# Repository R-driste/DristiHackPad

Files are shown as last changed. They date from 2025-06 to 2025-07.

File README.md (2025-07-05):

# DroydPad
Here is my hackpad for Athena/Highway in Hack Club! It includes 12 switches, an oled and a rotary encoder.
- You can find the pcb gerbers and 3d print files in the sub folders. Please print my case white so I can paint it later.
- My firmware turns the hackpad into a T-9 typing pad or a shortcuts simplifier (don't have to hold down multiple keys at once). The OLED displays what is currently happening and the rotary encoder changes the brightness of the screen.
- Pictures of my schematic and cad can be found in the general_files
<p align="center">
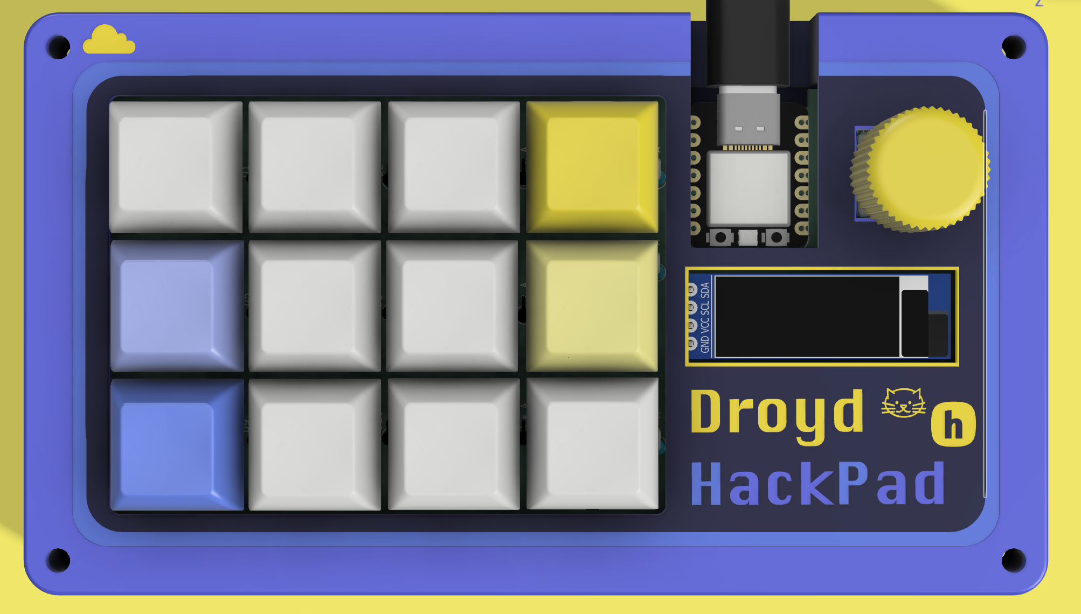
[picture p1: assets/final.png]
  
</p>

# Case CAD
Used Autodesk Fusion. In the cad_files folder I have attached my main cad file, my components (including the files needed to print the case) and components I borrowed from online (credits are below).
<p align="center">
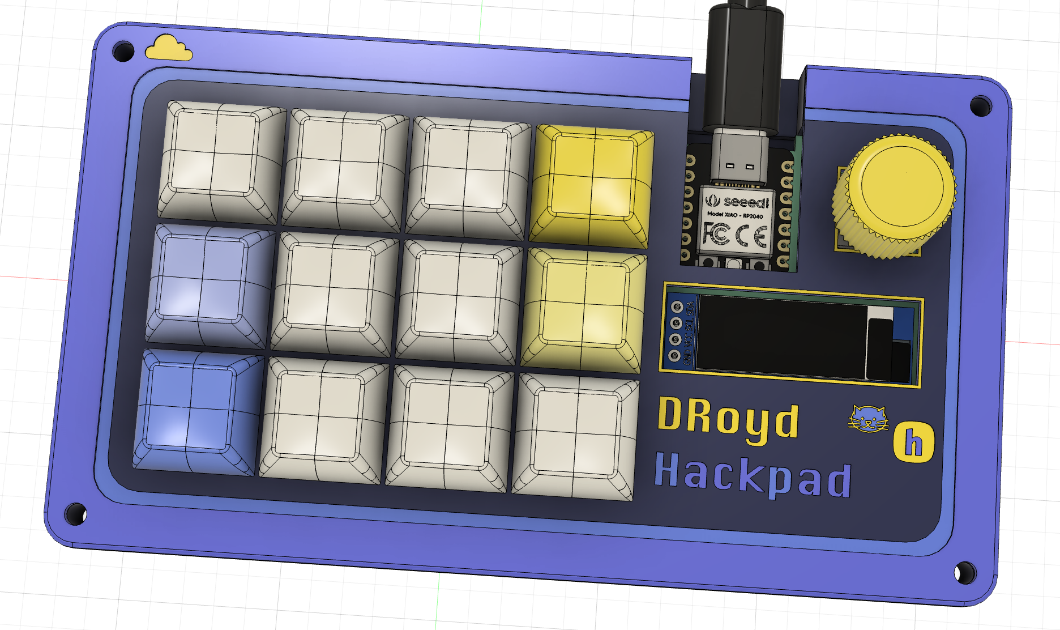
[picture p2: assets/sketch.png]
  
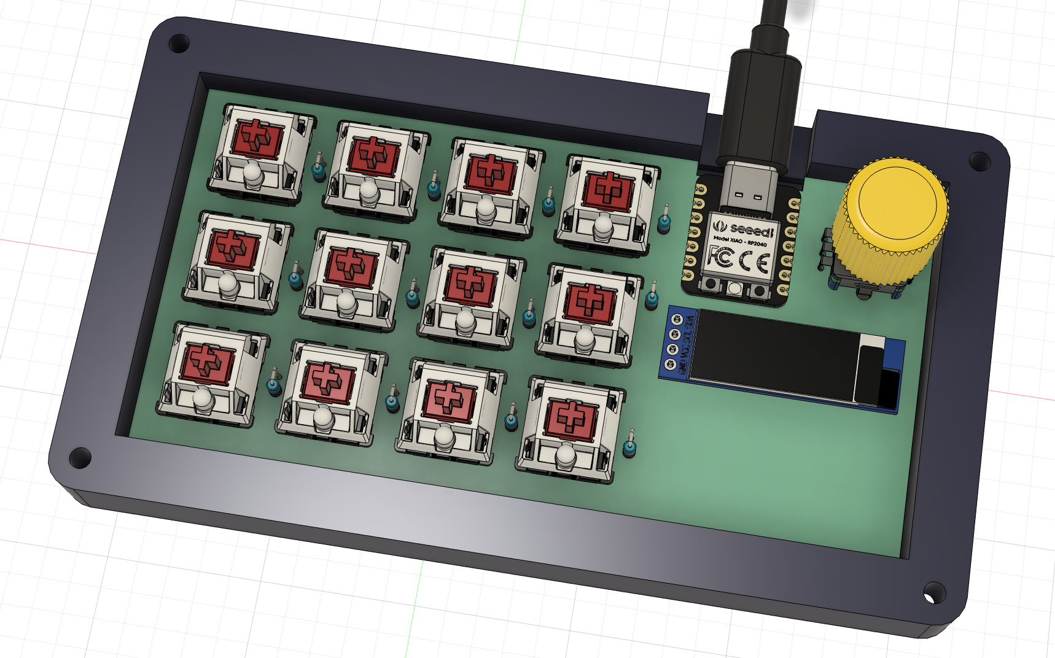
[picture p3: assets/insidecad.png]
  
</p>

# Schematic for PCB
- I designed the PCB in Kicad. In the kicad folder of the repository I attached my primary project files for the PCB.
<p align="center">
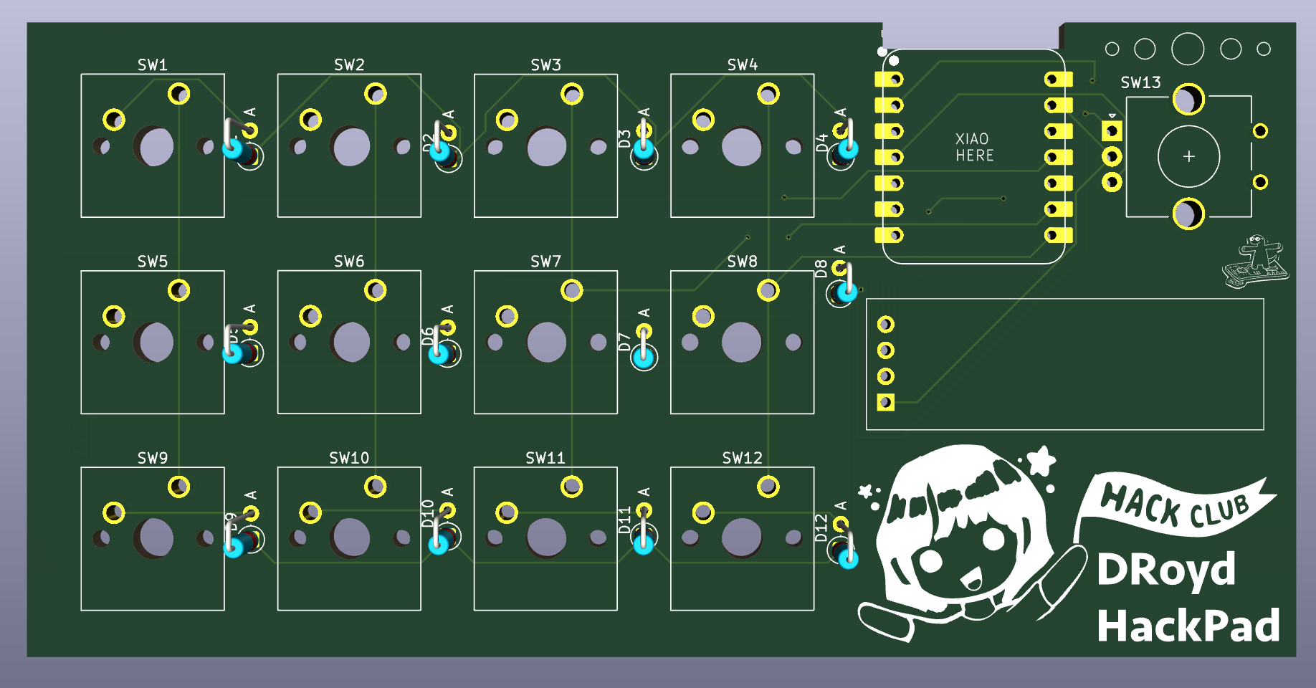
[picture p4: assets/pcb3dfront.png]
  
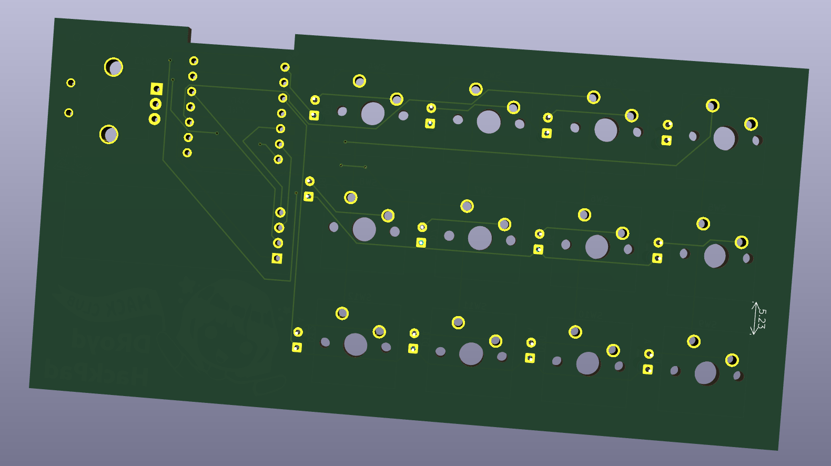
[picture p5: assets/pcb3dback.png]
  
</p>
<p align="center">
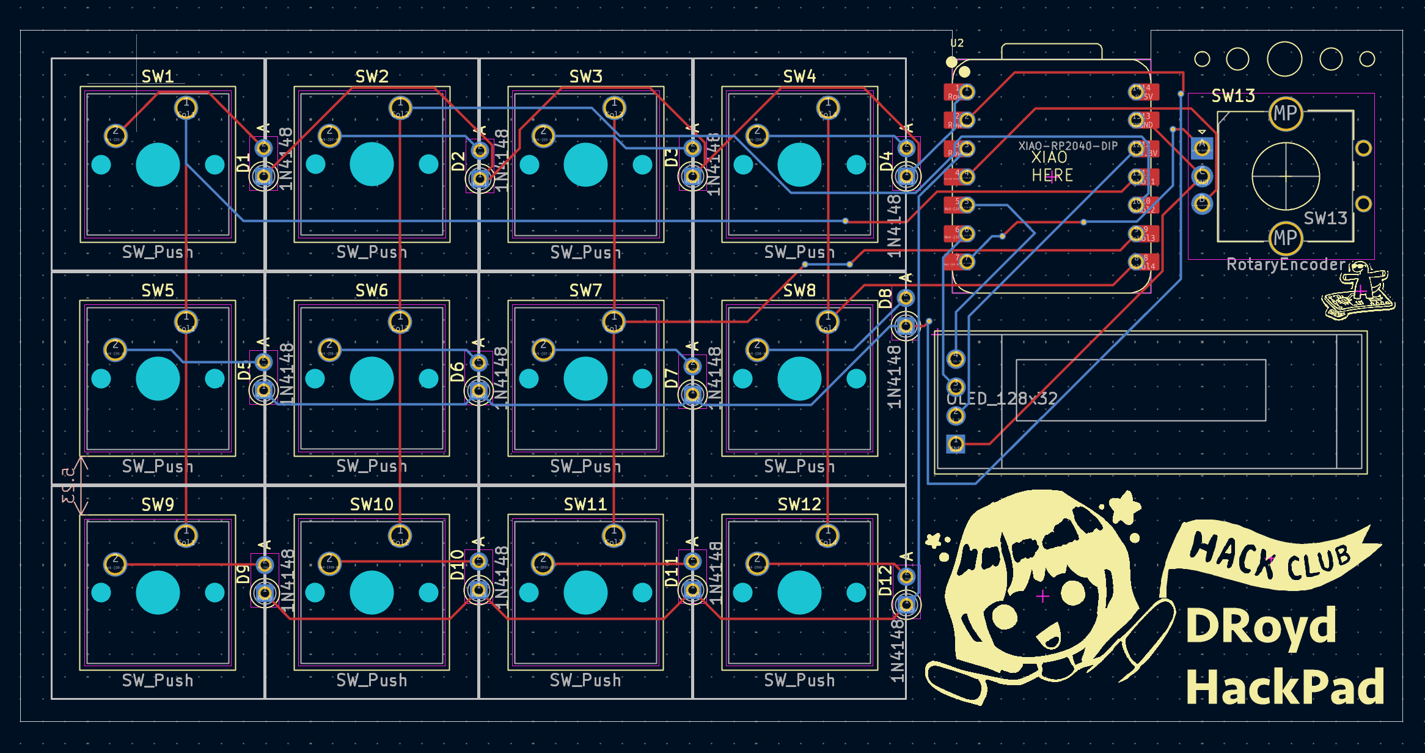
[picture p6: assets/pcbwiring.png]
  
</p>
<p align="center">
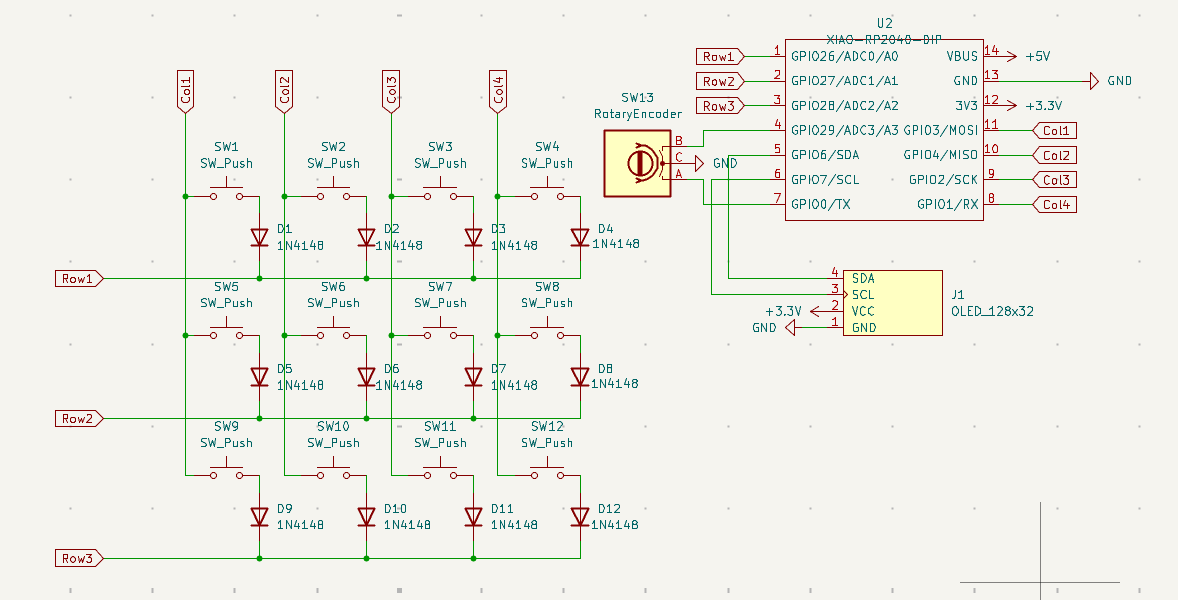
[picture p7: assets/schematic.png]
  
</p>

## BOM:
These should be the necessary parts to assemble this project.
#### From Kit
- 1x Seeed Studio Xiao RP2040
- 1x EC11E Rotary Encoder
- 1x 0.91" SSD1306 OLED screen
- 12x Cherry MX style switches
- 12x Blank DSA keycaps (white, will color)
- 12x DO-35 diodes
- 4x M3x16mm screws
- 4x M3x5mx4mm heatset inserts

#### For Print
- 1x Base Frame of Case
- 1x Top Cover of Case
- 1x Rotary Encoder Knob

+ the PCB of course.

## CREDITS
Online Components Links:
Cherry MX Switch Model -> https://grabcad.com/library/cherry-mx-red-switch-1 by Baco
DSA Keycap Model -> https://grabcad.com/library/dsa-keycap-for-cherry-mx-switches-1 by zim cad
USB-C Connector Model -> https://grabcad.com/library/usb-c-bulkhead-connector-1 by Nelson Stoldt
EC11 Rotary Encoder Model -> https://grabcad.com/library/ec11-rotary-encoder-with-switch-1 by Anthony Berkow
EC11 Rotary Encoder Knob Model -> https://www.printables.com/model/1000044-ec11-encoder-knob/files by Kea Workshop
Xiao Model -> https://grabcad.com/library/seeed-studio-xiao-rp2040-1 by mirac gulgonul
OLED 0.91 128x32 Model -> https://grabcad.com/library/oled-0-91-128x32-1 by Stilet Fox

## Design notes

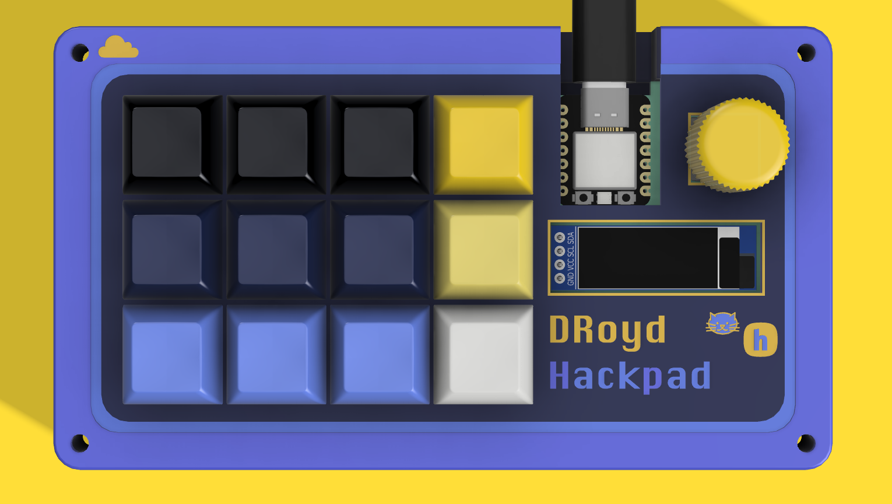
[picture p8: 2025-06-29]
assets/midrender.png

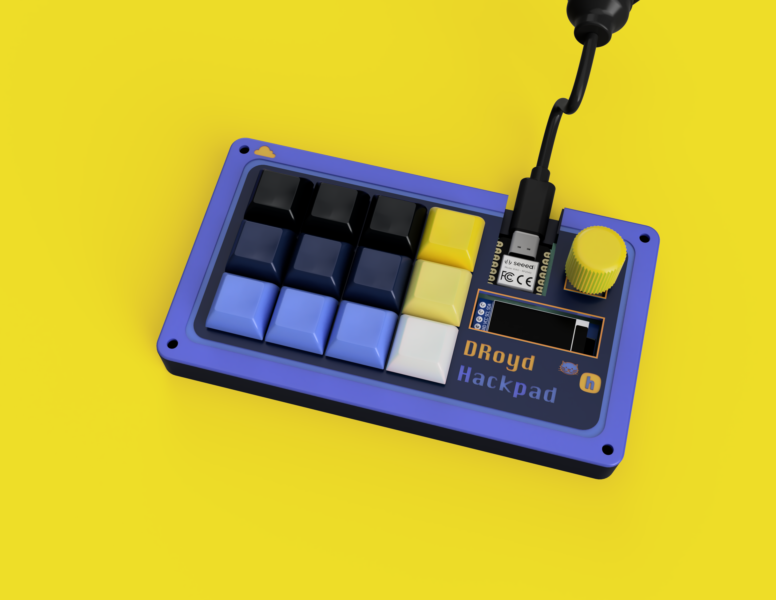
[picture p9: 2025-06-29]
general_files/highrender.png

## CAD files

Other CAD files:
production/Bottom.step
production/Top.step

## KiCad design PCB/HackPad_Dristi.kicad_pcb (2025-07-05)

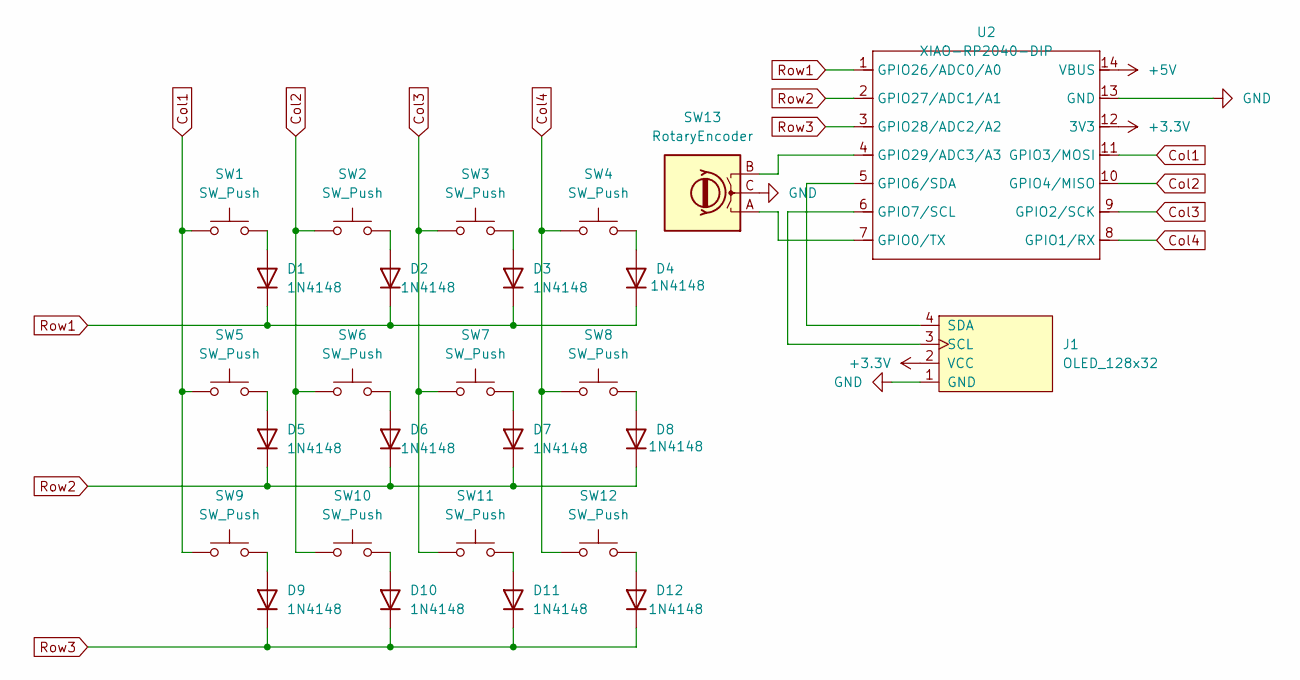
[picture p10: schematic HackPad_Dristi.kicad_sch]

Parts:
D1, D2, D3, D4, D5, D6, D7, D8, D9, D10, D11, D12: 1N4148; D_DO-35_SOD27_P2.54mm_Vertical_AnodeUp
J1: OLED_128x32
SW1, SW2, SW3, SW4, SW5, SW6, SW7, SW8, SW9, SW10, SW11, SW12: SW_Push; SW_Cherry_MX_1.00u_PCB
SW13: RotaryEncoder; RotaryEncoder_Alps_EC11E_Vertical_H20mm_CircularMountingHol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
U2: XIAO-RP2040-DIP

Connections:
+3.3V: J1.2 (VCC), U2.12 (3V3)
+5V: U2.14 (VBUS)
Col1: SW1.1, SW5.1, SW9.1, U2.11 (GPIO3/MOSI)
Col2: SW2.1, SW6.1, SW10.1, U2.10 (GPIO4/MISO)
Col3: SW3.1, SW7.1, SW11.1, U2.9 (GPIO2/SCK)
Col4: SW4.1, SW8.1, SW12.1, U2.8 (GPIO1/RX)
GND: J1.1 (GND), SW13.C, U2.13 (GND)
unnamed: D1.2 (A), SW1.2
unnamed: D2.2 (A), SW2.2
unnamed: D3.2 (A), SW3.2
unnamed: D4.2 (A), SW4.2
unnamed: D5.2 (A), SW5.2
unnamed: D6.2 (A), SW6.2
unnamed: D7.2 (A), SW7.2
unnamed: D8.2 (A), SW8.2
unnamed: D9.2 (A), SW9.2
unnamed: D10.2 (A), SW10.2
unnamed: D11.2 (A), SW11.2
unnamed: D12.2 (A), SW12.2
unnamed: J1.3 (SCL), U2.6 (GPIO7/SCL)
unnamed: J1.4 (SDA), U2.5 (GPIO6/SDA)
unnamed: SW13.A, U2.7 (GPIO0/TX)
unnamed: SW13.B, U2.4 (GPIO29/ADC3/A3)
Row1: D1.1 (K), D2.1 (K), D3.1 (K), D4.1 (K), U2.1 (GPIO26/ADC0/A0)
Row2: D5.1 (K), D6.1 (K), D7.1 (K), D8.1 (K), U2.2 (GPIO27/ADC1/A1)
Row3: D9.1 (K), D10.1 (K), D11.1 (K), D12.1 (K), U2.3 (GPIO28/ADC2/A2)

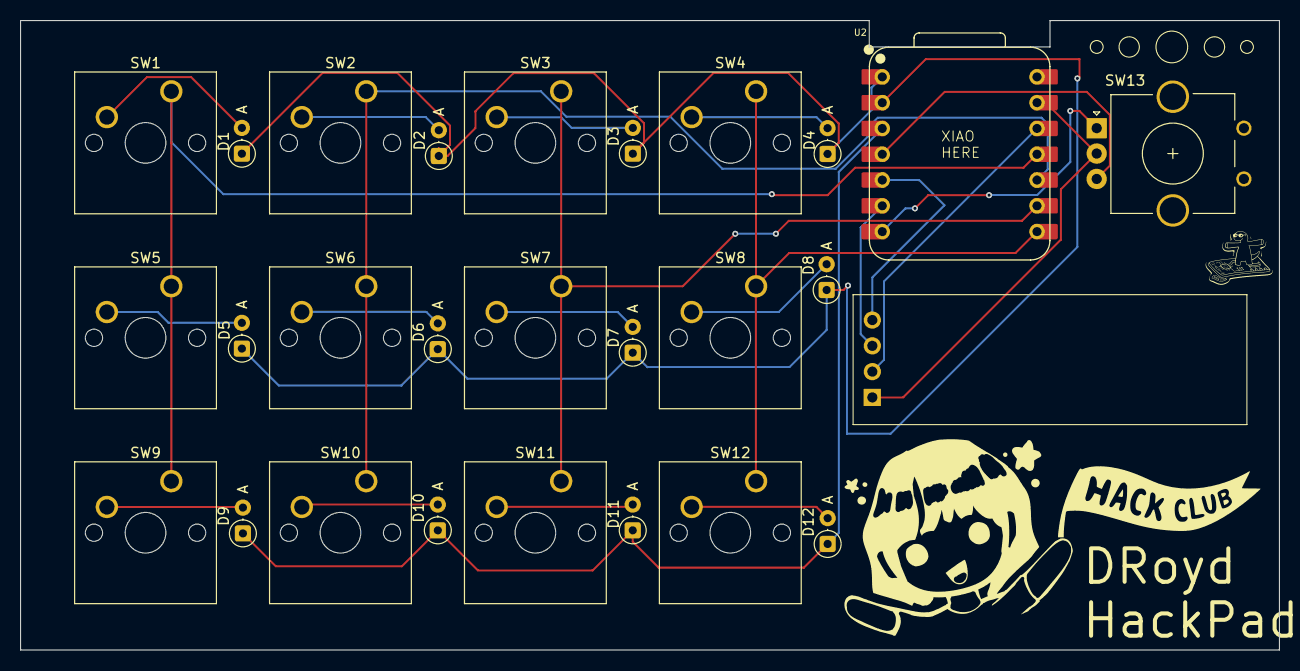
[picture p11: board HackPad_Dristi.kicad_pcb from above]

Board: 2 copper layers, 124.0 x 62.0 mm, 27 parts (0 on the bottom side), 25 nets.

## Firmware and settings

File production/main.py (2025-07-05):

import time
import board
import displayio
import terminalio

from kmk.kmk_keyboard import KMKKeyboard
from kmk.scanners import DiodeOrientation
from kmk.keys import KC
from kmk.modules.layers import Layers
from kmk.extensions.encoder import EncoderHandler
from kmk.extensions.OLED_SSD1306 import OLED
from kmk.kmk_module import KMKModule

#kmk setup
kbd = KMKKeyboard()
kbd.row_pins = (board.D0, board.D1, board.D2)
kbd.col_pins = (board.D11, board.D10, board.D9, board.D8)
kbd.diode_orientation = DiodeOrientation.COL2ROW

#encoder
encoder_ext = EncoderHandler(encoders=((board.D4, board.D7, None),), div=1)
kbd.extensions.append(encoder_ext)

#OLED config 
displayio.release_displays()
oled_ext = OLED(
    i2c          = board.I2C(),
    width        = 128,
    height       = 32,
    line_spacing = 1,
    font         = terminalio.FONT,
    to_display   = lambda kb: kb.oled_message
)
kbd.extensions.append(oled_ext)
kbd.oled_message = ''

#modes
SC, TP = 0, 1
kbd.modules.append(Layers())

keymap_shortcuts = [
    KC.LCTL(KC.C),
    KC.LCTL(KC.V),
    KC.LCTL(KC.X),
    KC.LCTL(KC.Z),
    KC.LCTL(KC.Y),
    KC.LCTL(KC.A),
    KC.LCTL(KC.TAB),
    KC.LCTL(KC.LSFT(KC.TAB)),
    KC.LALT(KC.F4),
    KC.LCTL(KC.LEFT),
    KC.LCTL(KC.RIGHT),
    KC.TO(TP),
]

keymap_typing = [
    KC.NO, KC.NO, KC.NO, KC.NO,
    KC.NO, KC.NO, KC.NO, KC.NO,
    KC.NO, KC.NO, KC.ENTER, KC.TO(SC),
]
kbd.keymap = [keymap_shortcuts, keymap_typing]

#brightness control module
class Brightness(KMKModule):
    def __init__(self, oled):
        self.oled = oled
        self._brightness = 1.0  # 0‑1
    def after_encoder(self, keyboard):
        pos = keyboard.encoders[0].position
        delta = pos - getattr(self, '_last_pos', pos)
        if delta:
            self._brightness = max(0, min(1, self._brightness + 0.1*(1 if delta>0 else -1)))
            self.oled.display.brightness = self._brightness
            keyboard.oled_message = f"Brightness: {int(self._brightness*100):3d}%"
        self._last_pos = pos
kbd.modules.append(Brightness(oled_ext))

#t9 style typing module
class T9(KMKModule):
    TAP_DELAY = 0.5
    MAX_CHARS = 21

    _map = {
        0: "1./",
        1: "2ABC",
        2: "3DEF",
        4: "4GHI",
        5: "5JKL",
        6: "6MNO",
        8: "7PQRS",
        9: "8TUV",
        10: "9WXYZ",
        3: "0 /",
    }

    def __init__(self):
        self.buffer = ''
        self.last_key = None
        self.last_time = 0
        self.tap_index = 0
        self._pending_char = None

    def process_key(self, keyboard, key, is_pressed, first_time):
        layer = keyboard.active_layers[0]
        if layer != TP or not is_pressed or not first_time:
            return True

        now = time.monotonic()

        #confirm current char
        if key == 7:
            if self._pending_char:
                self.buffer += self._pending_char
                keyboard.oled_message = self._trim(self.buffer.replace('\n', '/'))
                self._pending_char = None
                self.last_key = None
                self.tap_index = 0
            return False

        #switch mode
        if key == 11:
            keyboard.set_layer(TP)
            keyboard.oled_message = 'Typing Mode'
            return False

        if key in self._map:
            if self.last_key == key and (now - self.last_time) < self.TAP_DELAY:
                self.tap_index = (self.tap_index + 1) % len(self._map[key])
                keyboard.tap_key(KC.BSPC)
            else:
                self.tap_index = 0

            char = self._map[key][self.tap_index]
            if char == '/':
                keyboard.tap_key(KC.ENTER)
                char = '\n'
            else:
                keyboard.send_string(char)

            self._pending_char = char
            self.last_key = key
            self.last_time = now

            display_text = self.buffer + (char if char != '\n' else '/')
            keyboard.oled_message = self._trim(display_text)
            return False

        return True

    def _trim(self, txt):
        return txt[-self.MAX_CHARS:]

kbd.modules.append(T9())

if __name__ == '__main__':
    kbd.go()

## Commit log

2025-06-27 Add files via upload
    kicad add
    [HackPad_Dristi.kicad_pcb, HackPad_Dristi.kicad_sch]
2025-06-28 update components
    [Base_Frame.step, Cherry MX.step, DSA_Keycap_CherryMX.step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]
2025-07-05 updated format
    [Base_Frame.step, Bottom.step, Cherry MX.step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]
